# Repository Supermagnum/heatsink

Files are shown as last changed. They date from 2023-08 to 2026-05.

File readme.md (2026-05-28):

# DIY Liquid Cooling Suit

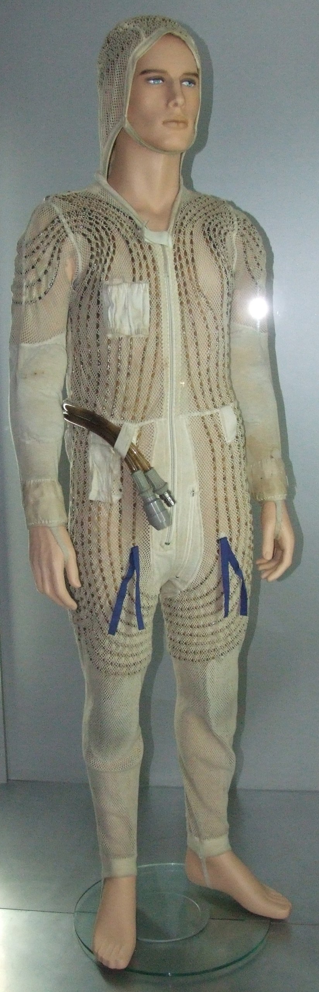
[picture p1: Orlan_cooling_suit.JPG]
Cooling Suit 1


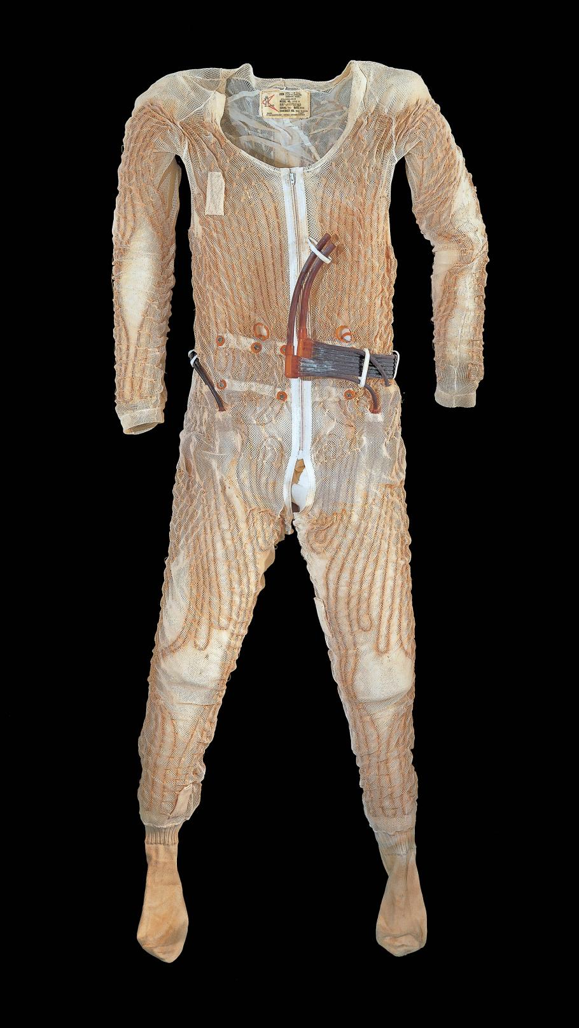
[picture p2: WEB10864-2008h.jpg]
Cooling Suit 2


Those are cooling suits, used in the lowest layer on space suits.
It has hoses for circulation of cooling medium. 
A single layer of fabric may be used, with the tubing either on the inside directly contacting the wearer's skin, or on the outside separated by the fabric. If two layers of fabric are used, stitched channels can be formed which enclose the tubing between the two fabric layers. Where flame resistance is needed, the garment may be constructed out of materials such as nomex. 
If anyone has seen the apollo 13 movie, the boxes carried by the astronauts on the way to the space capsule is a heat exchanger that provides cooling until the suits can be hooked up to the capsules internal cooling system.
That box also provides O2.

I think that NASA just used ice, battery and a pump in those boxes, and you need the capacity to at least transport 200W because the human body generates about 100W. One could rip out the heat exchanger from a car, the bit who heats air, make the suit out of spandex and sew in loops. Mesh cloth or mesh garments are also suitable. 
A radiator for a CPU liquid cooler should be ideal. Hook that up to a aquarium pump or similar, and the heat exchanger/radiator that goes in a bucket of ice cubes or phase shifting material and water. The pump will need to be able to flow around 4 liters per minute, and must run on 12V and accept PWM control.

The cooling loop is made of 
6 pvc hoses in parallel, measuring 6 mm ØID x 9 mm ØOD, length 4 meters per hose. Total internal surface of the hoses is 4524.7 cm². External surface 6789.6 cm2. The heat exchanger as well as hoses and pump contain 3 liters of inhibited propylene glycol and water mix (25–30%). Brass or metal connectors, hose barbs, and hose clamps should be used. Two manifolds are required — one for liquid distribution and one for collection — built from T-pieces, elbows, and other fittings (see [Coolant plumbing](#coolant-plumbing) below).

## Table of contents

- [Thermal Calculations](#thermal-calculations)
  - [Cooling 3 liters from 40°C to 18°C](#cooling-3-liters-of-waterglycol-from-40c-to-18c-in-150-seconds)
  - [Ice as a cooling medium](#ice-as-a-cooling-medium)
  - [Maintaining 18°C coolant temperature](#maintaining-18c-coolant-temperature)
  - [Liquid-to-ice heat exchanger](#liquid-to-ice-heat-exchanger)
- [Phase-Change Materials](#phase-change-materials)
- [Temperature Control](#temperature-control)
  - [Coolant options](#coolant-options)
  - [Preliminary Arduino Firmware](#preliminary-arduino-firmware)
- [Required Hardware](#required-hardware)
- [Electronics component list](component-list.md)
  - [Assembly instructions](component-list.md#assembly-instructions)
  - [Board placement guide (arduino-shield.jpg)](component-list.md#board-placement-guide)
  - [Ordering the PCB from Gerber files](component-list.md#ordering-the-pcb-from-gerber-files)
  - [Soldering and wire splicing](component-list.md#soldering-and-wire-splicing)
  - [How to solder (NASA reference)](component-list.md#how-to-solder)
  - [How to splice wire properly](component-list.md#how-to-splice-wire-properly)
  - [Heat-shrink on splices](component-list.md#heat-shrink-on-splices)
- [Wiring Diagram](#wiring-diagram)
- [12V Power Setup](#12v-power-setup)
  - [12V DC safety and dry locations](#12v-dc-safety-and-dry-locations)
- [Container Setup](#container-setup)
- [Suit Fabric](#suit-fabric)
- [Coolant plumbing](#coolant-plumbing)
- [Pump Selection](#pump-selection)

---

## Thermal Calculations

### Cooling 3 liters of water/glycol from 40°C to 18°C in 150 seconds

How much heat must be removed:

Q = mc∆T  
m = 3 kg  
Specific heat capacity of water = 4.18 J/g°C  
Temperature change: 40 - 18 = 22°C

Q = 3 kg × 4180 J/kg°C × 22°C = **275,880 J**

This means the heat exchanger removes 275,880 joules of heat from the cooling loop in 150 seconds.

To convert joules into watts: Joules / time in seconds = **~1,848W** during initial cooldown.

---

### Ice as a cooling medium

To remove 1848.8 watts of energy from 3 liters of water at 40°C over 150 seconds:

Q = P × t = 1848.8 W × 150 s = **277,320 J**

Mass of water being cooled:

m = Q / (c × ΔT) = 277320 / (4.18 × 40) ≈ **1.658 kg**

So approximately 1.65 kilograms of ice would be needed for the initial cooldown phase.

It will take approximately 42.86 seconds to remove 275,880 joules of heat with a flow rate of 5 liters per minute.

---

### Maintaining 18°C coolant temperature

With ambient air temperature at 40°C:

ΔT_initial = 40°C - 18°C = 22°C

m_ice = (m × c × ΔT_initial) / L_f  
m_ice = (3 kg × 4186 J/kg°C × 22°C) / 334,000 J/kg ≈ **0.827 kg per hour**

Including 100W body heat: approximately **~2 kg of ice per hour** is needed.  
Flow rate for maintenance: **~2.5 liters per minute**.

---

### Liquid-to-ice heat exchanger

To extract 275,880 J of heat from ice over 150 seconds using 10mm OD / 0.8mm wall copper tube with a ΔT of 40°C and convective heat transfer coefficient of 200 W/m²·K:

Required copper tube length: approximately **7.32 meters**  
Inner surface: 1.848 m²  
Outer surface: 2.198 m²

---

## Phase-Change Materials

I suggest using Cold Gel Packs, Campingaz or similar brand as they reportedly last longer than ice cubes.

You can make something similar yourself:  
https://m.youtube.com/watch?v=Nqxjfp4Gi0k

- Heat capacity of the salt/water mixture: approximately **5,451.5 J/°C**
- Latent heat: approximately **3.39 J/g°C**
- Total weight of mixture: **1,695 grams**
- Be aware that it might expand slightly when frozen.
- Heat capacity of 1,695 grams of water ice: approximately **3,543.55 J/°C**

Also look at:  
https://www.cryopak.com/solutions/refrigerants/phase-change-materials/phase-5/

- Heat capacity of 2 kg mixture: approximately **6,432.92 J/°C**
- Heat capacity of 2 kg water ice: **4,180 J/°C**
- 2 kg of the mixture will last approximately **3 hours** — much better than water ice.

---

## Temperature Control

To keep coolant at 18°C (0°C coolant is uncomfortable and risks hypothermia):

Use an automotive NTC temperature sensor and an Arduino to control temperature. Sensor datasheet: [Bosch M12 NTC temperature sensor (PDF)](https://www.bosch-motorsport.com/content/downloads/Raceparts/Resources/pdf/Data%20sheet_70101387_Temperature_Sensor_NTC_M12.pdf)

Arduino shield schematic: [arduino-shield.pdf](arduino-shield/arduino-shield.pdf) ([shield project folder](arduino-shield/))

Mount the Bosch M12 NTC in the **collection manifold** (return side), as close to the suit as possible — **not in the ice container**. This measures warm coolant leaving the suit for pump control. Use PWM to regulate pump speed from that reading.

Why **inhibited propylene glycol** and water? The ice bath and phase-change blocks can drive slush **below 0°C** at the heat exchanger. A **25–30% PG mix** keeps the loop liquid while staying thin enough to pump through 6 mm hoses. Unlike ethylene glycol antifreeze, propylene glycol is **biodegradable and low-toxicity** — a better fit near a wearable loop (still not for drinking). Use secure hose barbs and clamps, pressure-test the loop, and increase PG percentage only if slush goes colder than your mix rating.

### Coolant options

#### Recommended — inhibited propylene glycol + water (25–30% mix)

**Best balance of cost, safety, and compatibility for this build.**

| Property | Detail |
| --- | --- |
| **Toxicity** | Non-toxic, food-grade safe. Used in RVs, food processing, and HVAC. Unlike ethylene glycol, PG is biodegradable and presents a much lower hazard to people and animals if spilled. |
| **Hose / seal compatibility** | Compatible with typical cooling-system plastics and elastomers — PVC hose, pump seals, and brass barbs used in this project. |
| **Freeze point** | ~**−10°C at 25%** PG — enough margin for light sub-zero slush without the extra viscosity and pumping cost of a 50% mix. Use **30%** if you need more headroom. |
| **Electrical** | **Not dielectric** — conductivity is typically **>2,000 µS/cm** (water-based, conductive). Fine for a pumped hose loop; do not use near bare electronics expecting insulation. |
| **Cost / availability** | Cheapest practical option. Sold as pre-mixed **inhibited** PG antifreeze under names such as **DOWFROST**, **AMSOIL ANT**, **Cryo-Tek**, or generic **RV / marine antifreeze** at hardware and auto stores. Confirm the label says **propylene glycol**, not ethylene glycol. |

Mix with **distilled water** if buying full-strength concentrate; follow the label for your target freeze point.

#### Optional — ElectroCool and similar synthetic fluids

**ElectroCool** (Engineered Fluids) and similar **dielectric** immersion coolants are non-conductive and wash off with soap and water, but they are **much more expensive** and designed for electronics immersion — not as a default for this PVC-hose suit loop. Only consider if you validate compatibility with every hose, pump seal, and fitting, and accept the higher fluid cost.

#### Other alternatives

| Fluid | Notes |
| --- | --- |
| **USP / food-grade PG + water (DIY mix)** | Same family as above; buy PG concentrate and mix yourself. Lowest unit cost. |
| **Glycerol (glycerin) + water** | Non-toxic and biodegradable. Higher viscosity — may reduce flow in 6 mm hoses; weaker freeze protection per percent than PG. |
| **Potassium acetate / formate HTF** | Used in some commercial low-toxicity antifreeze systems. Verify pump, hose, and brass compatibility before use. |

#### Not recommended for a wearable loop

- **Ethylene glycol** (standard automotive antifreeze) — effective antifreeze but **acutely toxic**
- **Legacy PFAS / fluorinated fluids** — environmental persistence and regulatory phase-out
- **Plain water** — inadequate when slush goes below 0°C at the heat exchanger

#### Fill and service

- Use **distilled water** for mixing; tap water minerals cause scale and biofilm
- Pressure-test after fill; monitor for leaks on first runs (see [Coolant plumbing](#coolant-plumbing))
- Label the container and suit loop as containing glycol — not potable

### Preliminary Arduino Firmware

Two **momentary** switches adjust coolant temperature between 15°C and 25°C in 5°C steps (up/down).  
A **maintained toggle** switch on D4 enables manual pump override (full PWM on D9); off returns to automatic temperature control.  
Outputs on the [Arduino shield](arduino-shield/arduino-shield.pdf):
- **D9 → Q1 (TIP120):** pump PWM (temperature-controlled, or manual override via D4)
- **D7:** buzzer — out-of-ice alarm (>30°C for 2 minutes)
- **D8 → Q2 (TIP120):** spare 12V output (not used in current firmware)

LCD shows: target temperature, sensed temperature, current pump PWM.

Firmware repository:  
https://github.com/Supermagnum/heatsink/tree/main/firmware

---

## Required Hardware

1. **Arduino Uno R3** — bottom of the stack; see [component list](component-list.md)
2. [Heatsink control shield](arduino-shield/arduino-shield.pdf) — stacks on the Uno; [placement diagram](arduino-shield/arduino-shield.jpg) shows part positions, diode direction, and **+** wire marks. Order bare PCBs from [`arduino-shield/gerbers/`](arduino-shield/gerbers/) ([how to submit Gerbers](component-list.md#ordering-the-pcb-from-gerber-files)), then follow [assembly instructions](component-list.md#assembly-instructions). New to soldering? **20 W iron** and NASA/splice guides in [component list — Soldering and wire splicing](component-list.md#soldering-and-wire-splicing)
3. **LCD shield, 20×4, no buttons** — HD44780 display-only shield on top of the stack (not an LCD Keypad Shield)
4. NTC thermistor, [Bosch M12](https://www.bosch-motorsport.com/content/downloads/Raceparts/Resources/pdf/Data%20sheet_70101387_Temperature_Sensor_NTC_M12.pdf) (see [Coolant plumbing](#coolant-plumbing) for mounting)
5. **R1** — **MFP50SBBE52-50K** (50 kΩ, 0.1%) — DigiKey **MFP50SBBE52-50K-ND**
6. **D1–D3** — three **1N5407RL** flyback diodes — DigiKey **1N5407RL-ND** (or **1N5407RLG-ND** if unavailable)
7. **2× M3 nylon bolt and nut** — mount **Q1** and **Q2** tabs only; **no metal** hardware (12 V)
8. Shield stacking headers — DigiKey **1528-1074-ND** (Adafruit #85), one kit per bare control shield for Uno/LCD stack ([full DigiKey list](component-list.md#digikey-quick-order-bare-shield-populate))
9. Three **panel switches** on **SW1–SW3** (1×3 headers): two **100SP4T1B2M2QE** momentary (temp up/down), one **ANT13SECQE** maintained toggle (pump manual/auto). **Switch guards** (100SP / ANT compatible) recommended to prevent accidental actuation — especially on SW3
10. 12V submersible pump (4–5 L/min) — switched by **Q1 TIP120 on D9** on the control shield (max **5A**)
11. Optional: **5A inline fuses** on each 12V power cable branch (see [12V Power Setup](#12v-power-setup))
12. Crimped leads / screw terminals for panel switches, NTC, and 12 V — see [component list](component-list.md)
13. Hose clamps
14. Assorted T-pieces, elbows, connectors, adapters, and tube barbs (metal or PETG — see [Coolant plumbing](#coolant-plumbing))
15. Inhibited propylene glycol antifreeze (propylene, not ethylene) for 25–30% coolant mix
16. Liquid gasket or PTFE thread tape for sealed joints
17. Optional: small valves to control "zones"

### Arduino stack and connections

**Stack (bottom → top):** Arduino Uno R3 → heatsink control shield → **LCD shield without buttons**. Panel switches and NTC connect to the control shield headers/terminals only.

- Bosch M12 NTC (TH1) and 50K resistor (R1) form a voltage divider on A0; AREF feeds the divider top and sets the ADC reference
- **LCD shield** (20×4, HD44780, **no keypad**) on D12, D11, D10, D6, D5, D13 — see [Wiring Diagram](#wiring-diagram)
- Switches wired **pin → switch → GND** (active when grounded); firmware enables internal pull-ups on D2, D3, and D4
- **D2 / D3:** momentary — one temperature step per actuation
- **D4:** maintained toggle — ON = manual pump override, OFF = automatic
- D9 PWM drives **Q1 TIP120** on the shield — low-side switch for the pump (up to 5A)
- D7 drives the **buzzer** alarm output
- D8 drives **Q2 TIP120** for the spare 12V output
- Q1 and Q2 are TO-220 packages clamped to **built-in copper thermal zones** with **M3 nylon bolt and nut** each — **no metal mounting hardware** (12 V on the tab). **No add-on heatsinks**; the PCB spreads heat from the transistor tabs

---

## Wiring Diagram

Signal and power connections for the [Arduino shield](arduino-shield/arduino-shield.pdf). Ground all 12V loads to a common bus.

```mermaid
graph TD
    PSU["12V PSU / Battery"]

    PSU -->|12V| ARD["Arduino Uno\n+ control shield"]
    PSU -->|12V| Q1["TIP120 Q1\npump D9"]
    PSU -->|12V| Q2["TIP120 Q2\nspare D8"]

    ARD -->|D9 PWM| Q1
    Q1 --> PUMP["Submersible pump\n4–5 L/min"]

    ARD -->|D7| BUZ["Buzzer\nout-of-ice alarm"]
    ARD -->|D8| Q2
    Q2 --> SPARE["Spare 12V load\n(no firmware control)"]

    AREF["AREF-voltage"] -->|divider top + ADC ref| ARD
    AREF --> R1["R1 50K"]
    R1 -->|Vsense A0| ARD
    R1 --- TH1["TH1 Bosch M12 NTC\ncollection manifold\nat suit"]
    TH1 --> GND["Common GND"]

    SW1["SW1 Temp up\nmomentary"] -->|D2 — GND when closed| ARD
    SW2["SW2 Temp down\nmomentary"] -->|D3 — GND when closed| ARD
    SW3["SW3 Pump override\nmaintained toggle"] -->|D4 — GND when ON| ARD

    LCD["LCD 20x4"] -->|D12 RS, D11 E, D10 D4\nD6 D5, D13 D7| ARD

    ARD --- GND
    Q1 --- GND
    Q2 --- GND
    PUMP --- GND
    PSU --- GND
```

### Pin summary

| Pin | Function |
| --- | --- |
| A0 | NTC sense (R1 / TH1 junction) |
| AREF | Divider reference (same rail as R1 top) |
| D2 | SW1 momentary — target temperature up (+5°C per actuation) |
| D3 | SW2 momentary — target temperature down (−5°C per actuation) |
| D4 | SW3 maintained toggle — manual pump override (ON = full PWM) |
| D7 | Buzzer alarm (auto, >30°C for 2 min) |
| D8 | Q2 spare 12V output |
| D9 | Pump PWM via Q1 TIP120 |
| D5, D6, D10–D13 | LCD data and control |

**Switch wiring:** Panel switches **100SP4T1B2M2QE** (SW1, SW2) and **ANT13SECQE** (SW3) connect via **SW1–SW3** headers: **pin → switch → GND**. Internal pull-ups are enabled in firmware (`INPUT_PULLUP`); closed / ON = LOW. Add **switch guards** (100SP / ANT series) on the panel to reduce accidental toggles — especially on the pump override (SW3).

**NTC placement:** TH1 threads into the **collection manifold** on the return path, positioned **as close to the suit as practical** — not in the insulated container. The sensor cable runs back to the Arduino shield.

**NTC divider:** `AREF-voltage — R1 (50K) — A0 — TH1 (Bosch M12) — GND`. Firmware calls `analogReference(EXTERNAL)` so ADC readings match the divider supply.

**Pump override (SW3 / D4):** Maintained toggle — **ON** = full pump PWM via Q1; **OFF** = automatic temperature control.

**Temp switches (SW1 / SW2):** Momentary — one ±5°C step per actuation (debounced).

**12V loads:** Pump current flows through **Q1** on the shield — not through Arduino I/O pins directly. Q2 switches the spare load. D7 drives the buzzer. Add a **5A inline fuse** on each 12V feed (Arduino, pump/Q1, Q2) if not already fused at the battery.

---

## 12V Power Setup

```mermaid
graph LR
    BAT["12V Battery\nor PSU"]

    BAT --> FUSE_MAIN["Fuse 5A max\n(battery lead)"]
    FUSE_MAIN --> BUS["12V Distribution Bus"]

    BUS --> FUSE_A["Fuse 5A"] --> ARD["Arduino + LCD\n(~1A max)"]
    BUS --> FUSE_B["Fuse 5A"] --> PUMP_RAIL["Q1 pump rail\n(up to 5A)"]
    BUS --> FUSE_C["Fuse 5A"] --> Q2_RAIL["Q2 spare output"]

    GND["Common Ground Bus"] --- ARD
    GND --- PUMP_RAIL
    GND --- Q2_RAIL
    GND --- BAT
```

**Notes:**
- All components share a common ground
- Use **5A inline fuses maximum** on each 12V power cable branch (battery lead plus Arduino, pump/Q1, and Q2 feeds). Do not exceed 5A fuse rating on these cables
- The Arduino can be powered directly from 12V via its barrel jack (onboard regulator handles 5V/3.3V internally)
- The pump is switched by **Q1 TIP120 on the control shield** (D9 PWM) — do not connect pump current through Arduino pins
- Q1 and Q2 are rated up to 5A; size the pump accordingly
- Use appropriately rated wire gauge: 1.5mm² minimum for pump circuit, 0.5mm² for signal wiring
- TIP120 transistors (Q1, Q2) mount to **copper thermal zones** on the shield PCB with **M3 nylon** bolt and nut — **do not use metal** fasteners at the tabs; no separate heatsinks needed

**Battery sizing (portable use):**
- Pump draw: approximately 3-5A at 12V = 36-60W (Q1 TIP120 and pump fuse at **5A max**)
- Arduino + transistors + LCD: approximately 0.3A = 4W
- Total: approximately 4-5A continuous with a 5A fuse on the pump feed at the upper limit — avoid sustained overload
- A 20Ah 12V LiFePO4 battery gives approximately 3-4 hours runtime, matching the phase-change block duration

### 12V DC safety and dry locations

12 V is low enough that it is not mains shock hazard, but this system can still draw **several amps continuously**. Treat wiring like any other DC power installation: fused, correct gauge, and kept away from coolant and condensation.

**Electrical safety (12 V DC):**

- **Fuse every branch** at **5 A maximum** (battery lead plus Arduino, pump/Q1, and Q2). Fuses protect wire and battery from shorts — not optional.
- **Wire gauge:** **1.5 mm² minimum** on pump and battery feeds; **0.5 mm²** for signals. Undersized wire heats up under 3–5 A load.
- **Polarity:** Double-check **+12 V and GND** before connecting the battery. Reverse polarity can destroy the Arduino, shield, and pump controller.
- **One common ground** for battery, Arduino stack, pump return, and Q1/Q2 switching. Do not rely on the suit or frame as a ground path.
- **Pump current through Q1 only** — never through Arduino pins. The TIP120 switches the low side; the pump (+) comes from the fused 12 V bus.
- **Q1 / Q2 tab fasteners:** **M3 nylon** bolt and nut only — **no metal** at the transistor tabs (live **12 V**).
- **De-energize for wiring** — disconnect the battery or remove fuses when crimping, moving terminals, or opening the control enclosure.
- **Strain relief and insulation** — no bare copper at the panel or inside the box; use screw terminals or crimps where possible. **Every soldered splice must be covered with heat-shrink** (the [splice reference video](component-list.md#soldering-and-wire-splicing) does not show this step). Tie down cables so connectors are not pulled loose in use.
- **Coolant is conductive** — a glycol leak onto bare 12 V terminals can cause shorts, heating, or fire. Keep splices out of drip paths; wipe spills before re-energizing.
- **Batteries:** Use a proper 12 V pack (e.g. LiFePO4) with a BMS or charger matched to the chemistry. Do not short the terminals; store and charge in a dry, ventilated area away from flammable material.

**Keep dry — control unit and related electronics:**

Mount the **control unit** in a **dry enclosure** outside the ice container. It consists of:

| Keep dry | Location |
| --- | --- |
| **Arduino Uno R3 + heatsink control shield + LCD shield** (stacked) | Inside a sealed project box or small case on the suit harness, belt, or backpack — **not** in the cooler |
| **12 V battery** (if portable) | Same dry area as the control unit; protect from sweat, rain, and spills |
| **Panel switches** (SW1–SW3) | On the operator panel; guards help mechanically — use splash-aware routing if exposed |
| **NTC cable (TH1)** | Sensor threads into the **wet** manifold; only the **M12 sensor tip** sees coolant. The cable and connector back to the shield must stay **dry** — route upward from the manifold and seal the panel penetration |

**Allowed to get wet (by design):**

| Wet location | Parts |
| --- | --- |
| **Inside the insulated cooler** | Submersible pump, radiator, ice/slush, coolant hoses through the lid |
| **Suit loop** | PVC hoses, manifolds, fittings, and the Bosch M12 sensing element in the collection manifold |

Only **12 V pump power** and **coolant hoses** should pass through the cooler lid (grommeted or sealed). Run signal and Arduino power from the **dry control box** — do not submerge the stack, battery, or unsealed junctions. If the enclosure may see humidity, use vented or IP-rated boxes and keep connectors inside the lid line.

See also [Container Setup](#container-setup) for lid penetrations and [component list](component-list.md) for stack parts.

---

## Container Setup

```mermaid
graph TD
    LID["Insulated Cooler Lid\n(15-20 litre cooler)"]

    LID -->|Sealed penetrations| HOSE_IN["Coolant hose IN\n(warm return from suit)"]
    LID -->|Sealed penetrations| HOSE_OUT["Coolant hose OUT\n(chilled supply to suit)"]
    LID -->|Sealed penetrations| POWER["12V power cable\n(to pump)"]

    subgraph CONTAINER["Insulated Container (interior)"]
        RAD["240mm PC Radiator\n(submerged, bottom-mounted)"]
        PUMP_S["Submersible Pump\n(brushless 12V DC)"]
        ICE["Ice / Phase-Change Blocks\n(~2kg per hour runtime)"]
        WATER["Water filling gaps\nfor thermal contact"]
        RAD --- ICE
        PUMP_S --- ICE
        ICE --- WATER
    end

    HOSE_IN -->|warm coolant from suit| RAD
    RAD -->|cooled coolant| PUMP_S
    PUMP_S -->|cooled coolant| HOSE_OUT
```

**Container notes:**
- Use a quality foam-insulated cooler (camping/outdoor grade) with a good lid seal
- The radiator sits at the bottom, fully submerged in ice water — this gives 5-10× better heat transfer than air cooling
- The submersible pump also sits inside the container, drawing chilled water/glycol
- All lid penetrations (hoses and **pump 12 V power only**) should be sealed with silicone or grommets to prevent warm air ingress and leaks
- The **Arduino control unit** (stack, battery, dry wiring) stays **outside** the cooler — see [12V DC safety and dry locations](#12v-dc-safety-and-dry-locations)
- Fill gaps around ice/phase-change blocks with water to maximise thermal contact with the radiator
- The NTC sensor is **not** mounted in the container — it sits in the **collection manifold at the suit** (see [Coolant plumbing](#coolant-plumbing))

**Radiator sizing:**
- A 240mm radiator (air-rated ~300W) performs at approximately 1,500-3,000W when submerged in ice water
- This comfortably covers the 1,848W initial cooldown load and the 100W maintenance load
- A 360mm radiator provides additional headroom, particularly useful with phase-change blocks which have less uniform surface contact than liquid ice water

---

## Suit Fabric

**Recommended: Cotton mesh**

Cotton mesh is the best choice for this application because:
- Breathable open weave allows direct skin contact with the cooling tubes
- Cotton is comfortable and non-irritating against skin during extended wear
- Natural fibre — does not trap heat against the body
- Easy to sew channels or loops for routing the 6mm/9mm PVC hoses
- Washable and durable

**Construction:**
- Sew hose channels directly into the mesh using a zigzag or channel stitch
- Route hoses in parallel loops across the torso, back, and limbs as needed
- Connect the six suit hoses to distribution and collection manifolds (see [Coolant plumbing](#coolant-plumbing))
- Optional zone valves allow sections of the suit to be isolated, reducing flow to areas not needed

---

## Coolant plumbing

Two manifolds are needed: one splits flow from the supply line into the six parallel suit hoses, and one merges the return lines back toward the heat exchanger.

**NTC sensor placement:**
- Install the Bosch M12 sensor (TH1) in the **collection manifold** — the return manifold where warmed coolant from the suit hoses combines
- Place the port **as close to the suit as possible**, before the long hose run back to the container
- The sensor measures coolant temperature **leaving the suit**, which is what the Arduino uses for pump control — not the chilled fluid inside the ice box

**Fittings:**
- Several T-pieces, elbows, and connectors sized for 6 mm ID / 9 mm OD hose
- Metal (brass) barbs and fittings are the most durable option
- Manifolds can alternatively be **3D printed in PETG** if wall thickness and infill are high enough for pressure (typically 40% infill or higher, with solid perimeters around barb ports)

**Bosch M12 sensor mounting (metal route):**
- A suitable **drill and M12 tap** are required to thread the port for the Bosch M12 sensor
- Seal threads with **liquid gasket** or **PTFE tape**

**Assembly and testing:**
- Use liquid gasket or PTFE tape on all threaded connections
- **Pressure-test** the completed loop before use and **monitor for leaks** during initial runs
- Fix any weeping joints before relying on the system in service
- Electronics build and bench test: [assembly instructions](component-list.md#assembly-instructions) (Steps 5–6)

---

## Pump Selection

**Requirements:**
- 12V DC brushless, submersible rated
- Flow rate: 4-5 liters/minute (minimum)
- Continuous duty rated
- PWM controllable (dedicated PWM signal wire preferred)
- ½ inch inlet and outlet
- Compatible with inhibited propylene glycol and water mix (25–30%)

**Search terms:**
- "12V DC brushless submersible pump PWM 5LPM"
- "12V DC pump 300LPH PWM control"

Check aquarium suppliers, solar pump suppliers, and irrigation suppliers. Gear and diaphragm pumps handle PWM better than centrifugal types at this flow rate. Centrifugal pumps require priming and cannot be controlled as precisely.

**PWM control note:** The shield uses **Q1 TIP120** on D9 for low-side PWM of the pump. Many brushless pumps tolerate slow PWM on the power side; if the pump stutters, try a pump with a dedicated PWM input wire or add a smoothing capacitor on the pump supply. Stay within the **5A** Q1 and fuse limit.

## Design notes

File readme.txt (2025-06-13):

A DIY cooling suit idea:
Cooling Suit 1

Cooling Suit 2

Those are cooling suits, used in the lowest layer on space suits.
It has hoses for circulation of cooling medium. 
A single layer of fabric may be used, with the tubing either on the inside directly contacting the wearer's skin, or on the outside separated by the fabric. If two layers of fabric are used, stitched channels can be formed which enclose the tubing between the two fabric layers. Where flame resistance is needed, the garment may be constructed out of materials such as nomex. 
If anyone has seen the apollo 13 movie, the boxes carried by  the astronauts on the way to the space capsule is a heat exhanger that provides cooling until the suits can be hooked up to the capsules internal cooling system.
That box also provides O2.

I think that NASA just used ice,battery and a pump in those boxes, and you need the capacity to at least transport 200W because the human body generates about 100W. One could rip out the heat exhanger from a car, the bit who heats air, make the suit out of spandex and sew in loops.Mesh cloth or mesh garments are also suitable. 
A radiator for a CPU liquid cooler should be ideal.Hook that up to a aquarium pump or similar, and the heat exhanger/radiator that goes in a bucket of ice cubes or phase shifting material and water. The pump will need to be able to flow around 4 liters per minute, and must run on 12V and accept PWM control.

The cooling loop is made of 
6 pvc hoses in parallel, measuring 6 mm ØID x 9 mm ØOD, length 4 meters per hose. Total internal surface of the hoses is 4524.7 cm². External surface 6789.6 cm2. The heat exchanger as well as hoses and pump contain 3 liters of water/glycol mix. Brass or metal connectors,hose barbs  liquid distribution manifolds with hose clamps should be used.

Thermal calculation examples:
One cools 3 liters of water/glycol from 40 degrees to 18 degrees in 150 seconds.

How much heat must be removed:
Q = mc∆T
m = 3 kg.

specific heat capacity of water is 4.18 J/g°C, one liter of water is 1000 grams.

And we know that the temperature change of the water is 40 - 18 = 22 °C.

So by entering these values into the formula we get:
Q = 3 kg x 4180 J/kg°C x 22 °C Q = 275880 J

This means that the heat exchanger removes 275880 joules of heat from the cooling loop in 150 seconds.

To convert joules into watts= Joules/time in seconds.

Ice as a cooling medium for the coolant loop:

To calculate the amount of ice needed to remove 1848.8 watts of energy from 3 liters of water at 40 degrees Celsius over a period of 150 seconds, we can use the formula:

Q = P * t

Where:
Q = Heat energy (in Joules)
P = Power (in watts)
t = Time (in seconds)

Given that P = 1848.8 watts and t = 150 seconds, we can calculate Q:

Q = 1848.8 W * 150 s
Q = 277320 J

Now, let's use the specific heat capacity formula to determine the mass of water being cooled:

Q = m * c * ΔT

Where:
Q = Heat energy (in Joules) = 277320 J
m = Mass of the substance (in kilograms)
c = Specific heat capacity of water (approximately 4.18 J/g°C)
ΔT = Change in temperature (final temperature - initial temperature)

We know that the initial temperature of water is 40°C and it's being cooled to 0°C  in this case (assuming ice temperature). Solving for the mass (m):

m = Q / (c * ΔT)
m = 277320 J / (4.18 J/g°C * 40°C)
m ≈ 1658,6 g

Converting grams to kilograms:

m ≈ 1.658 kg

So, approximately 1.65 kilograms of ice (equivalent to the mass of water being cooled) would be needed to remove 1848.8 watts of energy from 3 liters of water/glycol mix at 40 degrees Celsius over a period of 150 seconds. 

It will take approximately 42.86 seconds to remove 275,880 joules of heat with a flow rate of 5 liters per minute.

Now, when the coolant has reached 18 degrees Celsius say we want to keep it at that temperature.

How one can calculate the amounts of ice needed per hour to keep the coolant liquid at 18 degrees Celsius if the ambient air temperature is 40 degrees Celsius:
First, we need to calculate the initial temperature difference between the water and the ambient air:

ΔT_initial = 40°C - 18°C = 22°C

Next, we calculate the heat transfer required to bring the water to its final temperature:

Q = m * c * ΔT_initial

Since we're interested in how much ice is needed to absorb this heat, we can also equate it to the heat absorbed by melting ice:

Q = m_ice * L_f

Where:
- m_ice is the mass of ice (in kilograms)
- L_f is the heat of fusion of ice (334,000 J/kg)

Combining the two equations:

m_ice * L_f = m * c * ΔT_initial

Solving for m_ice:

m_ice = (m * c * ΔT_initial) / L_f

Given that the density of water is approximately 1000 kg/m³, the mass of 3 liters of water is 3 kg.

m_ice = (3 kg * 4186 J/kg°C * 22°C) / 334000 J/kg ≈ 0,827 kg

So, approximately 0,827 kilograms ( 827 grams) of ice per hour would be needed to keep 3 liters of water at 18 degrees Celsius when the ambient air temperature is 40 degrees Celsius.
But, one needs to include that a human body generates maximum 100W of heat, so the mass of ice needed per hour is ≈ 2 kg
The flow rate for that is around 2.5 liters per minute.

Liquid to ice heat exhanger:
To extract 275,880 J of heat from water ice over 150 seconds using a 10 mm OD and 0.8 mm wall thickness copper tube with a temperature difference of 40 degrees Celsius and a convective heat transfer coefficient of 200 W/m²·K, the required length of the copper tube is approximately 7.32 meters. That is a inner surface of 1,848 square metres, and 2,198 square metres.

Keep in mind that these calculations assumes ideal heat transfer and doesn't consider other factors that might affect the cooling process, loss to the environment, heat exhanger loss and so on..

They also assumes that I haven't made any mathematical bloopers.

I suggest using Cold Gel Packs, Campingaz or similar brand as they supposedly lasts longer that ice cubes.

You can make something similar yourself:
https://m.youtube.com/watch?v=Nqxjfp4Gi0k
The heat capacity of the salts and water mixture is approximately 5451.5 J/°C.
In latent heat that is around 
3.39J/g°C.
The total weight of the mixture is 1695 grams. Be aware that it might expand slightly when frozen.
The heat capacity of 1695 grams of water ice is approximately 3543.55 J/°C.

Also,look at:
https://www.thermalcustompackaging.com/pcm/

The heat capacity of the 2 kg mixture is approximately 6432.92 J/°C.
The heat capacity of 2 kg of water ice is 4180 J/°C.
2 kilos of the mixture will last about 3 hours.
Much better than water ice.

How does one keep the temperature of the coolant at 18 degrees Celsius, 0 degrees coolant is uncomfortable!
There's also a risk of hyperthermia!

One can use a automotive NTC temperature sensor like this, and a arduino to control the temperature:
https://www.bosch-motorsport.com/content/downloads/Raceparts/Resources/pdf/Data%20sheet_70101387_Temperature_Sensor_NTC_M12.pdf
One then can monitor the temperature of the suits output and use PWM control to  control the speed of a pump.

Why water/glycol mix? So that the liquid in the coolant loop does not freeze or turn to slush in the heat exchanger.

Preliminary firmware for Arduino and the mentioned temperature sensor:
It has two switches, to adjust the coolant temperature between 15 degrees and 25 degrees Celsius in 5 degree steps.
One for up, one for down. 
I also has another switch to start the pump.
It has 2 relay outputs, one activates if the coolant temperature goes over 30 degrees Celsius for a set time. It can be used to activate a buzzer to signal out of ice.
It also puts out the wanted temperature, sensed temperature and current pump pwm to a 4 line lcd screen.
https://github.com/Supermagnum/heatsink/tree/main/firmware

### Required Hardware:
1. Arduino board (e.g., Arduino Uno)
2. NTC thermistor, Bosch M12.
3. Resistor (50k ohms)
4. 4-line LCD (compatible with LiquidCrystal library)
5. Three guarded stsp switches (for temperature up, temperature down, and relay control)
6. Pump controlled via PWM
7. Two relays,12V
8. Breadboard and connecting wire
9.3 10K resistors.
10. hose clamps.
11. Assorted size adapters and tube barbs in metal.
12: optional small valves to control "zones".

### Connections:
- NTC thermistor and 50k resistor form a voltage divider.
- LCD connected to appropriate digital pins.
- Switches connected to digital pins with pull-down resistors.
- PWM pin connected to pump control input.
- Digital pins connected to relay control inputs.

### Notes:
1. **Debouncing**: The debounce logic ensures that button presses are not registered multiple times due to mechanical bounce.
2. **Temperature Calculation**: The resistance of the NTC is converted to a temperature value using a linear interpolation method between calibration points.
3. **PWM Control**: The PWM value is adjusted based on the difference between the target temperature and the read temperature, with a minimum PWM of 10%.
4. **LCD Display**: The LCD shows the target temperature, the read temperature, the current PWM value, and the state of the relay.

### Adjustments:
- Ensure that the LCD pin connections in the code match your actual connections.
- Modify pin numbers if you use different pins for buttons, relays, or the NTC sensor.
- If the NTC thermistor has different calibration values, adjust the `tempValues` and `resistanceValues` arrays accordingly.

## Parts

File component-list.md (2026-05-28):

# Electronics component list

Bill of materials for the Arduino control side of the liquid cooling suit. Values match the [control shield schematic](arduino-shield/arduino-shield.pdf). KiCad source files in `arduino-shield/` are maintained separately and are not edited from this repo workflow.

**Assembly goal:** stack shields on an **Arduino Uno R3** with **minimum soldering** — plug-in headers and screw terminals for field wiring; only populate/solder the control shield PCB if you order it bare. If you are new to soldering, see [Soldering and wire splicing](#soldering-and-wire-splicing) below.

## Table of contents

- [Stack (bottom to top)](#stack-bottom-to-top)
- [Core components](#core-components)
- [Control shield](#control-shield-included-in-stack)
  - [DigiKey quick order (bare shield populate)](#digikey-quick-order-bare-shield-populate)
- [Assembly instructions](#assembly-instructions)
  - [Board placement guide](#board-placement-guide)
  - [Before you start](#before-you-start)
  - [Step 1 — Populate the bare control shield](#step-1--populate-the-bare-control-shield)
  - [Step 2 — Build the Arduino stack](#step-2--build-the-arduino-stack)
  - [Step 3 — Panel switches and NTC](#step-3--panel-switches-and-ntc)
  - [Step 4 — 12 V power and pump](#step-4--12-v-power-and-pump)
  - [Step 5 — Load firmware](#step-5--load-firmware)
  - [Step 6 — Bench test](#step-6--bench-test)
- [Ordering the PCB from Gerber files](#ordering-the-pcb-from-gerber-files)
- [Wire and cable](#wire-and-cable-minimum-soldering)
- [Soldering and wire splicing](#soldering-and-wire-splicing)
  - [How to solder (NASA reference)](#how-to-solder)
  - [How to splice wire properly](#how-to-splice-wire-properly)
  - [Heat-shrink on splices](#heat-shrink-on-splices)
- [Quick wiring reference](#quick-wiring-reference)
- [Suggested order checklist](#suggested-order-checklist)
- [12 V safety and enclosure](#12-v-safety-and-enclosure)

---

## Stack (bottom to top)

| Layer | Part | Notes |
| --- | --- | --- |
| 1 | **Arduino Uno R3** | ATmega328P, 5 V logic. Powers from 12 V barrel jack or VIN when on battery. |
| 2 | **Heatsink control shield** | [arduino-shield.pdf](arduino-shield/arduino-shield.pdf) + [placement diagram](arduino-shield/arduino-shield.jpg) — stacking headers, Q1/Q2, R1, D1–D3, TH1 header, SW1–SW3 headers, buzzer, 12 V pump/spare terminals. Solder only if you receive a bare PCB. |
| 3 | **LCD shield (no buttons)** | 20×4 HD44780, **display only** — no keypad, no built-in push-buttons. Plugs onto the stack; uses D5, D6, D10–D13 (see [pin summary](readme.md#pin-summary)). Do **not** use an LCD Keypad Shield — firmware uses external panel switches on D2–D4. |

External to the stack (crimp or screw terminals, no board soldering): **three panel switches**, **Bosch M12 NTC** cable to TH1 header, **12 V** pump and power leads.

---

## Core components

| Qty | Ref | Description | Part number / spec | Notes |
| --- | --- | --- | --- | --- |
| 1 | U1 | Microcontroller | **Arduino Uno R3** | Required for direct shield stacking. |
| 1 | — | LCD shield | **20×4 HD44780 LCD shield, no buttons** | e.g. parallel “LCD2004” shield without keypad. Display-only — temp/PWM/alarm text; switches stay on the panel. |
| 1 | TH1 | NTC temperature sensor | **Bosch M12** NTC | [Datasheet (70101387)](https://www.bosch-motorsport.com/content/downloads/Raceparts/Resources/pdf/Data%20sheet_70101387_Temperature_Sensor_NTC_M12.pdf). Mount in **collection manifold** at the suit (return path), not in the ice box. Requires **M12 tap** and sealant on metal manifold. |
| 1 | R1 | Fixed resistor, top of NTC divider | **MFP50SBBE52-50K** (50 kΩ, 0.1%, 1/2 W) — DigiKey **MFP50SBBE52-50K-ND** | Solder on control shield between AREF rail and A0; TH1 from A0 to GND. |
| 3 | D1, D2, D3 | Flyback diode (inductive loads) | **1N5407RL** (DO-27, 3 A) — DigiKey **1N5407RL-ND** (or **1N5407RLG-ND** if RL is unavailable) | One each across Q1, Q2, and the spare 12 V path — cathode to +12 V, anode toward transistor collector (per [schematic](arduino-shield/arduino-shield.pdf)). |
| 2 | Q1, Q2 | NPN Darlington, low-side switch | **TIP120** (TO-220) | Q1: pump on **D9** (PWM, up to **5 A**). Q2: spare 12 V on **D8**. Mount to shield **copper thermal zones** with **nylon M3** bolt + nut each — **no metal fasteners** (12 V on tab). No add-on heatsinks. |
| 2 | — | Transistor mounting | **M3 nylon** bolt + nut (×2 sets) | One per **Q1** and **Q2** tab hole. **Do not use metal** screw/nut/washer — can short **12 V** to ground. |
| 2 | SW1, SW2 | Panel switch, momentary | **100SP4T1B2M2QE** | Temp up (D2) and temp down (D3). **Switch guard** recommended (see below). |
| 1 | SW3 | Panel switch, maintained toggle | **ANT13SECQE** | Pump manual/auto on **D4**. **Switch guard** strongly recommended — prevents accidental pump override. |
| 3 | — | Switch guard | Compatible with **100SP** / **ANT** panel switches | Optional but recommended: covers/guards that block accidental bumps (especially on SW3). Match guard to switch series and actuator type per supplier catalog. |

---

## Control shield (included in stack)

| Qty | Ref | Description | Part number / spec | Notes |
| --- | --- | --- | --- | --- |
| 1 | — | **Heatsink control shield** PCB | Gerbers in [`arduino-shield/gerbers/`](arduino-shield/gerbers/) | Bare board — populate per schematic PDF. |
| 1 | — | Shield stacking headers | **Adafruit #85** / DigiKey **1528-1074-ND** | One kit per bare shield: 2×6 + 2×8 + 1×10 long-tail stacking female for Uno R3 stack (control shield between Uno and LCD). |
| 1 | R1 | NTC divider resistor | **MFP50SBBE52-50K-ND** | Also listed under [Core components](#core-components). |
| 3 | D1–D3 | Flyback diodes | **1N5407RL-ND** (or **1N5407RLG-ND**) | Also listed under [Core components](#core-components). |
| 2 | Q1, Q2 | Darlington switches | **TIP120** + **M3 nylon** bolt/nut each | Also listed under [Core components](#core-components). **No metal** tab hardware. |
| 1 | BZ1 | Buzzer | TDK **PS1240P02BT** class, 12 mm, polarized | Alarm on **D7** (>30 °C for 2 min). |

Order assembled if you want zero soldering; on a bare PCB, solder stacking headers, TIP120 (to copper thermal zones with **nylon M3** hardware), R1, D1–D3, buzzer, and field connectors per the schematic PDF.

### DigiKey quick order (bare shield populate)

| Qty | DigiKey | Manufacturer P/N | Ref / use |
| --- | --- | --- | --- |
| 1 | [1528-1074-ND](https://www.digikey.com/en/products/result?keywords=1528-1074-ND) | Adafruit **#85** | Shield stacking headers (2×6 + 2×8 + 1×10) |
| 1 | [MFP50SBBE52-50K-ND](https://www.digikey.com/en/products/result?keywords=MFP50SBBE52-50K-ND) | MFP50SBBE52-50K | R1 — NTC divider |
| 3 | [1N5407RL-ND](https://www.digikey.com/en/products/result?keywords=1N5407RL-ND) | 1N5407RL | D1, D2, D3 — flyback (schematic value) |
| 3 | [1N5407RLG-ND](https://www.digikey.com/en/products/result?keywords=1N5407RLG-ND) | 1N5407RLG | Same as above if **1N5407RL-ND** is out of stock (lead-free replacement) |

Search DigiKey for **TIP120** and a **PS1240P02BT**-class buzzer separately; those parts are not Adafruit-line items.

See [Ordering the PCB from Gerber files](#ordering-the-pcb-from-gerber-files) to have bare boards fabricated.

---

## Assembly instructions

End-to-end build for the **Arduino control unit** (Uno + heatsink control shield + LCD shield + field wiring). Coolant plumbing, ice box, and suit hoses are covered in the [readme](readme.md) ([Coolant plumbing](readme.md#coolant-plumbing), [Container setup](readme.md#container-setup)).

### Board placement guide

Use the silkscreen labels and polarity marks on the bare PCB. This shield has **no USB** — only the **Arduino Uno** below it does. The render below is the **control shield alone** (component side up). Match its orientation: **D1** at the top of the diode column, **SW1–SW3** on the **right**, **stacking-header** holes along the long **top and bottom** edges:

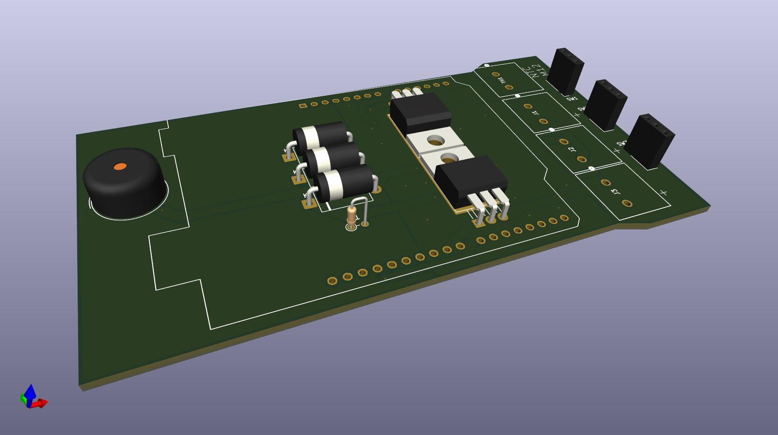
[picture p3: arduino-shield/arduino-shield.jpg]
Heatsink control shield — component placement and polarity


| Label | Location on board | What to install / connect |
| --- | --- | --- |
| **D1, D2, D3** | Left column (**D1** top, **D3** bottom) | **1N5407RL** — cathode **band toward D1** (same end as silkscreen **K** / +12 V side). |
| **R1** | Below the diode column | **MFP50SBBE52-50K**, vertical axial. |
| **BZ1** | Left side, round footprint | Polarized buzzer — **+** pin to marked **+** on silkscreen. |
| **Q1, Q2** | Centre, on copper thermal areas | **TIP120** — package **flat on the board**, metal tab on copper, leads bent **90°** toward the **bottom** long edge (same side as in the image). **Q1** above **Q2**. Secure each tab with an **M3 nylon bolt and nut** through the tab hole — **never metal** (12 V present). |
| **SW1, SW2, SW3** | Right edge, **three 3-pin blocks** in a row (top → bottom) | **1×3** sockets for panel switch cables — see [Step 3](#step-3--panel-switches-and-ntc). |
| **TH1** | Four 2-pin blocks, left of SW column (top block) | NTC cable — **+** silkscreen marks sense/reference; other pin is GND. |
| **J1, J2, J3** | Next blocks below **TH1** | Screw terminals — land **+12 V** on pins marked **+**; other pin is switched load or return per [Step 4](#step-4--12-v-power-and-pump). |
| *(headers)* | Top and bottom long rows | **1528-1074-ND** stacking headers for Uno / LCD stack. |

Every part has its own ref label (**SW1**, **Q1**, etc.) printed on the board — match those labels when placing parts.

### Before you start

**Tools:** 20 W soldering iron, rosin-core solder, damp sponge, flush cutters, small screwdriver for screw terminals, crimp tool (optional), multimeter, **2× M3 nylon bolt + nut** for **Q1** and **Q2** (no metal hardware at transistor tabs).

**Parts:** Complete the [suggested order checklist](#suggested-order-checklist) and [DigiKey quick order](#digikey-quick-order-bare-shield-populate) if you are populating a bare shield.

**Reference:** [arduino-shield.jpg](arduino-shield/arduino-shield.jpg) for placement and polarity; [arduino-shield.pdf](arduino-shield/arduino-shield.pdf) for electrical nets.

**Safety:** Work **de-energized** — no battery connected until [Step 6](#step-6--bench-test). See [12 V safety and enclosure](#12-v-safety-and-enclosure) and [Soldering and wire splicing](#soldering-and-wire-splicing).

**Skip PCB soldering** if someone else populated the control shield for you — start at [Step 2](#step-2--build-the-arduino-stack).

### Step 1 — Populate the bare control shield

Only when you received a **bare PCB** from the [Gerber order](#ordering-the-pcb-from-gerber-files). Follow the [board placement guide](#board-placement-guide) and silkscreen labels. Suggested solder order (shortest parts first, then connectors, then tall headers):

| Order | Ref | Part | Notes |
| --- | --- | --- | --- |
| 1 | R1 | **MFP50SBBE52-50K** | Vertical axial in the **R1** footprint below **D3**; trim leads flush on the bottom. |
| 2 | D1, D2, D3 | **1N5407RL** | In the left column (**D1** top, **D2** middle, **D3** bottom). **Cathode band toward D1** (toward **K** / +12 V), as in [arduino-shield.jpg](arduino-shield/arduino-shield.jpg). |
| 3 | BZ1 | **PS1240P02BT**-class buzzer | Round **BZ1** footprint on the left; align **+** on the part with the **+** mark on the board. |
| 4 | SW1, SW2, SW3 | **1×3 pin sockets** (2.54 mm) | Three blocks on the **right** — **SW1** top, **SW2** middle, **SW3** bottom. |
| 5 | TH1, J1, J2, J3 | **2-pin** terminals (Molex **393800102** class) | Four outlined pairs left of the switch column — **TH1** at top, then **J1**, **J2**, **J3**. Note each **+** mark for field wiring. |
| 6 | Q1, Q2 | **TIP120** + **M3 nylon** bolt/nut | Mount **flat** on the copper zones labelled **Q1** (upper) and **Q2** (lower): tab against copper, leads bent down toward the **bottom** edge, then solder. Clamp each tab through the hole with an **M3 nylon bolt and nut only** — **metal screws or nuts will short 12 V** to the board or frame. **No add-on heatsinks.** |
| 7 | — | **Stacking header kit** (1528-1074-ND) | Top and bottom rows — long pins down toward the **Uno**. Kit: **2×6**, **2×8**, **1×10**. Align with a spare Uno before soldering every pin. |

Inspect joints under good light; fix bridges and cold joints. Compare the finished board to [arduino-shield.jpg](arduino-shield/arduino-shield.jpg) and the schematic PDF.

### Step 2 — Build the Arduino stack

Stack order (**bottom → top**):

1. **Arduino Uno R3** on the bench (its **USB** port is on the Uno only — use any stable orientation).
2. **Heatsink control shield** — match [arduino-shield.jpg](arduino-shield/arduino-shield.jpg) when populating; then press stacking headers fully onto the Uno; all pins should seat without force on bent leads.
3. **LCD shield (20×4, no buttons)** — press onto the control shield. Do **not** use an LCD Keypad Shield (firmware expects external switches on **D2–D4**).

Mount the stack in a **dry project box** on the harness or pack — never inside the ice cooler ([readme — dry locations](readme.md#12v-dc-safety-and-dry-locations)).

### Step 3 — Panel switches and NTC

**Panel switches (SW1–SW3):** The three **3-pin blocks** on the right of the board (see [placement diagram](arduino-shield/arduino-shield.jpg)) are **SW1** (top), **SW2** (middle), and **SW3** (bottom). For each block, crimp a **3-position socket** and three leads (0.5 mm²):

| Header | Switch | Wiring |
| --- | --- | --- |
| **SW1** | **100SP4T1B2M2QE** (temp up) | **Middle pin** → switch → **either outer pin** (both outers are **GND**). Active = grounded (**D2**). |
| **SW2** | **100SP4T1B2M2QE** (temp down) | Same — middle pin is **D3**. |
| **SW3** | **ANT13SECQE** (pump manual/auto) | Same — middle pin is **D4**. **ON** = grounded = manual pump override. |

The silkscreen **+** on each switch block marks the pin row orientation — use the **centre pin** for the Arduino signal, not the **+** mark, when wiring a simple two-terminal panel switch. Install **switch guards** on the panel, especially on SW3.

**NTC (TH1):** Top **2-pin** block in the terminal column (**TH1**). Connect the NTC cable to the pins marked on the board (**+** = sense / **A0** divider node, other = **GND**). Mount the **Bosch M12** sensor in the **collection manifold** ([readme — NTC placement](readme.md#coolant-plumbing)). Keep the connector and cable **dry** — only the sensor tip sees coolant.

### Step 4 — 12 V power and pump

Wire with **battery disconnected** and **fuses removed**.

1. **Common ground bus** — tie Arduino GND, battery (−), pump return, and Q1/Q2 emitter returns to one point (star ground in the box).
2. **Fused 12 V distribution** — **5 A max** inline fuse on the battery lead and on each branch: Arduino (barrel jack or VIN), pump **+** rail to **Q1**, spare **+** to **Q2** ([12 V power setup](readme.md#12v-power-setup)).
3. **Pump (Q1, D9)** — On **J1** (and related pump terminals), land **+12 V** on the pin marked **+**; switched/return on the other pin. **+12 V** (fused) → pump **+**; pump **−** → **Q1** low-side output; common **GND**. Use **≥1.5 mm²** wire. Do **not** pass pump current through Arduino pins.
4. **Spare output (Q2, D8)** — **J2** / **J3** same pattern: **+** silkscreen = **+12 V** in; other pin to load return through **Q2** if used.
5. **Polarity check** — verify **+12 V** and **GND** with a multimeter before connecting the battery.

See [Quick wiring reference](#quick-wiring-reference) and the [wiring diagram](readme.md#wiring-diagram).

### Step 5 — Load firmware

1. Connect the Uno to a PC via **USB** (stack can stay assembled; 12 V battery still **off**).
2. Open `firmware/pump-control.ino` in the Arduino IDE (or install from the [firmware folder](https://github.com/Supermagnum/heatsink/tree/main/firmware)).
3. Select board **Arduino Uno** and the correct serial port.
4. Upload. The **20×4 LCD** should show target temperature, sensed temperature, and PWM after boot.

### Step 6 — Bench test

With the **coolant loop filled and leak-checked** before long runs ([readme — assembly and testing](readme.md#coolant-plumbing)):

| Check | Action | Expected |
| --- | --- | --- |
| Power | Connect **fused 12 V**; USB optional for serial debug | LCD on; no excessive heating on wiring |
| NTC | Warm the sensor tip slightly (hand or warm water) | Sensed temperature on LCD changes smoothly |
| SW1 / SW2 | Tap temp up/down | Target steps **15–25 °C** in **5 °C** steps |
| SW3 | Toggle pump override **ON** | Pump runs at full PWM; **OFF** returns to auto control |
| Pump auto | SW3 **OFF**; vary NTC temperature | PWM changes with temperature error |
| Alarm | Simulate over-temp (>30 °C for 2 min) or heat sensor | Buzzer on **D7** sounds |
| 12 V load | Run pump at duty for several minutes | Q1 tab warm but stable; fuses do not blow; no melt/smoke |

Monitor the first field runs for leaks, fuse trips, and connector heat. Fix any weeping coolant joints before extended use.

---

## Ordering the PCB from Gerber files

Production-ready Gerbers for the heatsink control shield are in the repo — you do **not** need KiCad to order boards. Use the files in:

**[`arduino-shield/gerbers/`](arduino-shield/gerbers/)**

### What is in the folder

| File | Purpose |
| --- | --- |
| `arduino-shield-F_Cu.gbr` | Top copper |
| `arduino-shield-B_Cu.gbr` | Bottom copper |
| `arduino-shield-F_Mask.gbr` / `B_Mask.gbr` | Solder mask (top / bottom) |
| `arduino-shield-F_Silkscreen.gbr` / `B_Silkscreen.gbr` | Silkscreen legend |
| `arduino-shield-F_Paste.gbr` / `B_Paste.gbr` | Solder paste (for SMT assembly only — ignore if you hand-solder) |
| `arduino-shield-Edge_Cuts.gbr` | Board outline |
| `arduino-shield-PTH.drl` | Plated through-hole drill hits |
| `arduino-shield-NPTH.drl` | Non-plated holes (if any) |
| `arduino-shield-job.gbrjob` | Job metadata (layer stack, thickness) — optional but helps some fabs |

Board spec from the job file: **2-layer FR4**, **1.6 mm** thick, outline roughly **92 × 61 mm** (Arduino Uno R3 shield form factor).

### How to submit to a PCB fab

1. **Download or clone** the repo and open `arduino-shield/gerbers/`.
2. **Select all** `.gbr` and `.drl` files in that folder (include both drill files).
3. **Zip** them into one archive (e.g. `arduino-shield-gerbers.zip`). Keep filenames unchanged — do not nest an extra subfolder unless the fab asks for it.
4. **Upload** the zip to a board house (e.g. JLCPCB, PCBWay, OSH Park, Aisler, or any fab that accepts standard Gerber + Excellon drill).
5. **Preview** the upload in the fab’s Gerber viewer before paying. Check outline, drill hits, and silkscreen alignment.
6. **Choose fab options** (typical for this board):

   | Option | Recommended |
   | --- | --- |
   | Layers | **2** |
   | Thickness | **1.6 mm** |
   | Material | **FR4** |
   | Copper weight | **1 oz** (default) |
   | Surface finish | **HASL** or **ENIG** (either is fine for through-hole) |
   | Solder mask | Any colour (default green is fine) |
   | Silkscreen | White or yellow on green mask |
   | PCB assembly / SMT | **No** — this shield is **through-hole**; you populate it yourself (see [Soldering and wire splicing](#soldering-and-wire-splicing)) |

7. **Quantity:** most fabs quote from **5 pcs** upward; one board is enough for a single suit, extras are spares.

### After the boards arrive

- Compare the bare PCB to [arduino-shield.pdf](arduino-shield/arduino-shield.pdf).
- Follow [Assembly instructions](#assembly-instructions) from Step 1 onward.

### Regenerating Gerbers (optional)

The committed Gerbers match the shield design at export time. To produce a new set you need **KiCad 9** and the project in `arduino-shield/` — open `arduino-shield.kicad_pcb`, run **File → Fabrication Outputs → Gerbers**, and plot to `gerbers/` with drill files included. Only do this if you maintain your own fork of the PCB; the repo’s `gerbers/` folder is the canonical release for ordering.

---

## Wire and cable (minimum soldering)

| Use | Spec | Length (typical) | Notes |
| --- | --- | --- | --- |
| **12 V power** — battery to Uno/shield, pump (+) via Q1, spare via Q2 | **1.5 mm²** (16 AWG) stranded, **≥5 A** | Container ↔ battery ↔ pump | Land on shield **screw terminals**. **5 A inline fuse** per branch. |
| **Pump return / load (−)** | Same as 12 V power | Same | Low-side through Q1/Q2; common GND bus. |
| **Panel switches SW1–SW3** | **0.5 mm²** (22 AWG) stranded | ~0.5–2 m per switch | **Crimp to 1×3 socket** on shield headers — no soldering at panel if you use pre-crimped leads. Wire **pin → switch → GND**. |
| **NTC (TH1)** | **0.5 mm²** twisted or shielded pair | Manifold → control box | Plug or screw to TH1 connector on shield; route away from pump motor and PWM power runs. |
| **Stack interconnect** | — | — | Uno ↔ control shield ↔ LCD shield via **1528-1074-ND** stacking headers on the control shield (solder one kit per bare PCB). |

**Connectors:** 1×3 **2.54 mm** socket housings + crimp pins for SW1–SW3; screw terminals on shield for 12 V and pump.

---

## Soldering and wire splicing

**Tools and consumables:**

- **20 W soldering iron** with a fine tip — enough for this PCB and signal wiring, not heavy power lugs
- **Proper solder** — rosin-core electrical solder (e.g. **60/40 tin/lead** or lead-free **Sn96.5**), fine diameter (~0.6–0.8 mm) for through-hole parts and splices
- **Wet sponge** for tip cleaning (keep it damp, not dripping) — standard bench practice alongside the NASA video below
- **Heat-shrink tubing** — **required on every soldered splice** (see below; not shown in the splice reference video)

If you order a **bare** control shield PCB, you will need to solder the through-hole parts (stacking headers, TIP120, R1, D1–D3, buzzer, and field connectors). Panel and 12 V wiring can mostly use **crimps and screw terminals**; any soldered splices must use proper technique **and** heat-shrink insulation so joints stay reliable and safe under vibration and humidity.

### How to solder

NASA training video — old but the workmanship standard is excellent:  
[https://www.youtube.com/watch?v=_RXugDd0xik](https://www.youtube.com/watch?v=_RXugDd0xik)

### How to splice wire properly

[https://www.youtube.com/watch?v=O-ymw7d_nYo](https://www.youtube.com/watch?v=O-ymw7d_nYo)

### Heat-shrink on splices

The splice video does **not** show finishing the joint — after soldering, **slide heat-shrink over the splice and shrink it fully** so no bare copper is exposed. Use tubing sized for your wire (typically slightly larger ID before shrinking); for 12 V runs, use heavier wall or double-layer shrink if the splice is in the harness. No exceptions for in-box or panel wiring.

Prefer **screw terminals or crimp connectors** on 12 V and switch runs where you can and skip splices entirely. When you must splice, follow the [splice video](#how-to-splice-wire-properly), then **always** heat-shrink. Work **de-energized** — battery disconnected and fuses out — see [12 V safety and enclosure](#12-v-safety-and-enclosure).

---

## Quick wiring reference

```
Stack:  Uno R3  →  control shield  →  LCD shield (no buttons)

AREF — R1 (50K) — A0 — TH1 (Bosch M12) — GND   (on control shield)

SW1/SW2/SW3:  header pin → switch → GND  (D2 / D3 / D4)  + switch guards

D9 → Q1 → pump (+)     pump (−) → GND
D8 → Q2 → spare load
D7 → buzzer
```

---

## Suggested order checklist

- [ ] Arduino Uno R3  
- [ ] Heatsink control shield — order bare PCB from [Gerber files](component-list.md#ordering-the-pcb-from-gerber-files) or populate one you already have  
- [ ] DigiKey bare-shield kit — [1528-1074-ND](https://www.digikey.com/en/products/result?keywords=1528-1074-ND) + [MFP50SBBE52-50K-ND](https://www.digikey.com/en/products/result?keywords=MFP50SBBE52-50K-ND) + 3× [1N5407RL-ND](https://www.digikey.com/en/products/result?keywords=1N5407RL-ND) (or 3× [1N5407RLG-ND](https://www.digikey.com/en/products/result?keywords=1N5407RLG-ND)) — see [DigiKey quick order](component-list.md#digikey-quick-order-bare-shield-populate)  
- [ ] 2× **TIP120** (Q1, Q2) + 2× **M3 nylon** bolt/nut + buzzer — see [Control shield](component-list.md#control-shield-included-in-stack)  
- [ ] LCD shield 20×4 **without buttons**  
- [ ] 1× Bosch M12 NTC + M12 tap + thread sealant  
- [ ] 2× 100SP4T1B2M2QE + guards  
- [ ] 1× ANT13SECQE + guard  
- [ ] 12 V wire (1.5 mm²) + switch leads (0.5 mm²) + crimp housings + fuses (5 A)  
- [ ] **20 W soldering iron**, **rosin-core solder**, **wet sponge**, and **heat-shrink tubing** (only if populating a bare control shield or making splices) — see [Soldering and wire splicing](component-list.md#soldering-and-wire-splicing)

---

## 12 V safety and enclosure

- **Q1 / Q2 mounting:** Use **M3 nylon bolt and nut** only at the TIP120 tabs. **Metal** screws, nuts, or washers can bridge **12 V** to ground or the enclosure and blow fuses or damage the board.
- **Control unit** (Uno + heatsink shield + LCD stack, battery, and dry-side wiring) must stay **dry** — mount in a project box on the harness or pack, **not** inside the ice cooler.
- **Fused 12 V** (5 A max per branch), **1.5 mm²** pump feeds, correct polarity, common ground — see [12V DC safety and dry locations](readme.md#12v-dc-safety-and-dry-locations) in the readme.
- Only the **submersible pump** and coolant path belong in the wet zone; seal lid glands for hose and pump power; keep NTC connector and Arduino wiring in the dry enclosure.

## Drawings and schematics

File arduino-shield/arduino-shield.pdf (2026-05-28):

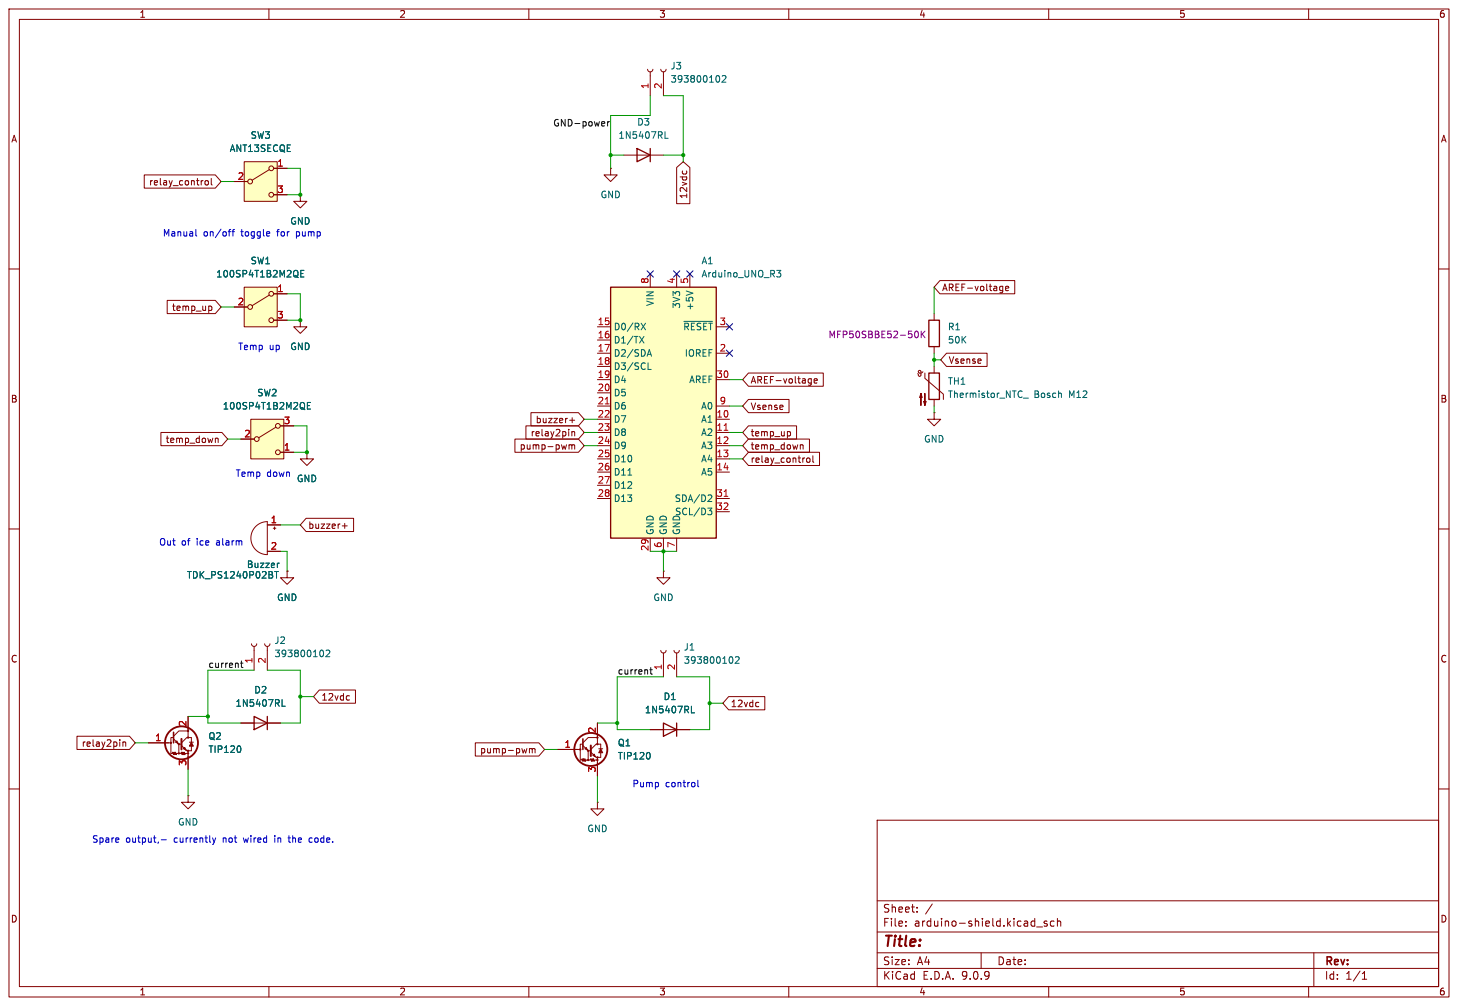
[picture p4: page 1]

Id: 1/1 Title: File: arduino-shield.kicad_sch Sheet: /

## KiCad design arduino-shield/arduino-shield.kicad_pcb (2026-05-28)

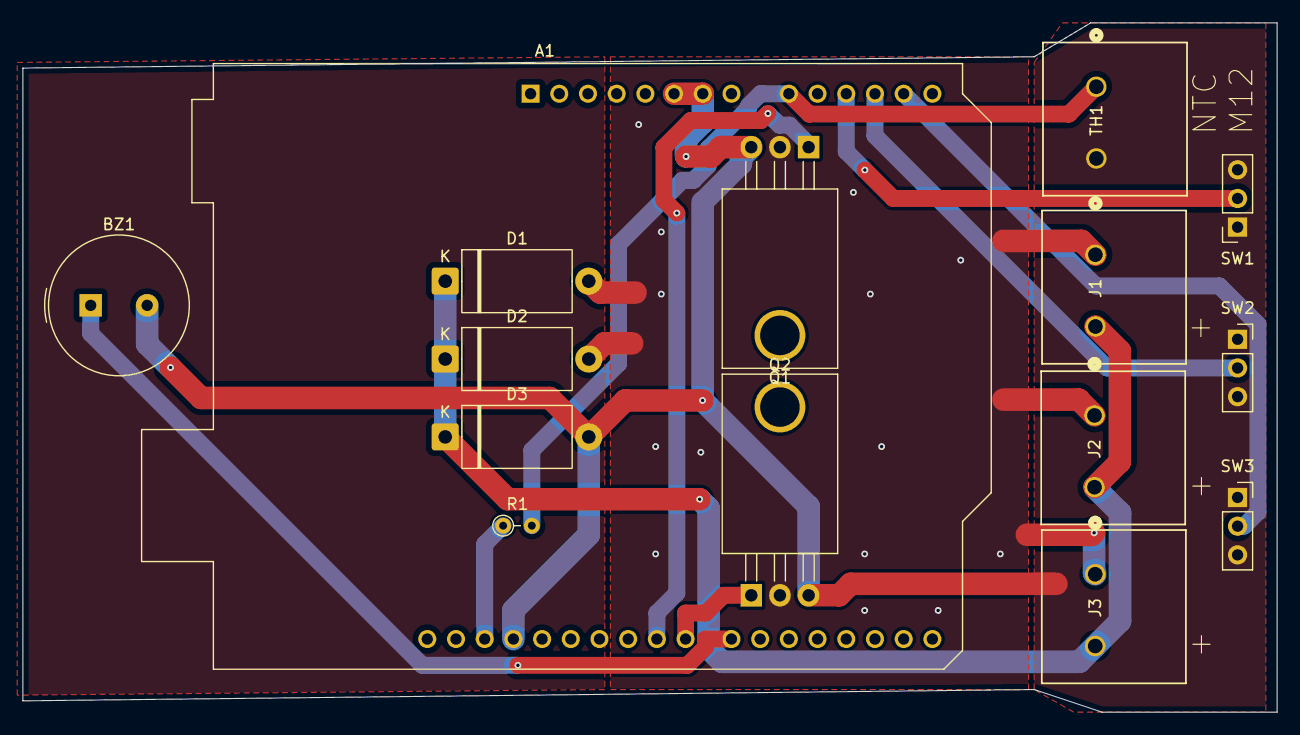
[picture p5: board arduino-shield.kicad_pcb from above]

Board: 2 copper layers, 111.0 x 61.0 mm, 15 parts (0 on the bottom side), 11 nets.

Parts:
A1: Arduino_UNO_R3; Arduino_UNO_R3_
BZ1: Buzzer; Buzzer_TDK_PS1240P02BT_D12.2mm_H6.5mm
D1, D2, D3: 1N5407RL; D_DO-27_P12.70mm_Horizontal
J1, J2, J3: 393800102; CONN2_0393800102_524X492_MOL
Q1, Q2: TIP120; TO-220-3_Horizontal_TabDown
R1: 50K; R_Axial_DIN0204_L3.6mm_D1.6mm_P2.54mm_Vertical
SW1, SW2: 100SP4T1B2M2QE; PinSocket_1x03_P2.54mm_Vertical
SW3: ANT13SECQE; PinSocket_1x03_P2.54mm_Vertical
TH1: Thermistor_NTC_ Bosch M12; CONN2_0393800102_524X492_MOL

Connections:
12vdc: D1.1 (K), D2.1 (K), D3.1 (K), J1.2, J2.2, J3.2
/current: D1.2 (A), D2.2 (A), J1.1, J2.1, J3.1, Q1.2 (C), Q2.2 (C)
AREF-voltage: A1.30 (AREF), R1.1
GND: A1.6 (GND), A1.7 (GND), A1.29 (GND), BZ1.2 (-), D3.2 (A), Q1.3 (E), Q2.3 (E), SW1.1 (A), SW1.3 (C), SW2.1 (C), SW2.3 (A), SW3.1 (A), SW3.3 (C), TH1.2
Vsense: A1.9 (A0), R1.2, TH1.1
buzzer+: A1.22 (D7), BZ1.1 (+)
pump-pwm: A1.24 (D9), Q1.1 (B)
relay2pin: A1.23 (D8), Q2.1 (B)
relay_control: A1.13 (A4), SW3.2 (B)
temp_down: A1.12 (A3), SW2.2 (B)
temp_up: A1.11 (A2), SW1.2 (B)

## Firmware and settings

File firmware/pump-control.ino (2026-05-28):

#include <LiquidCrystal.h>

// LCD1602 LDC
// ── Pin assignments ───────────────────────────────────────────────────────────
// LCD uses pins 12, 11, 10, 6, 5, 13
// Switches and other I/O use pins 2, 3, 4, 7, 8, 9 — no conflicts
const int ntcPin              = A0;  // Vsense — R1/TH1; TH1 in collection manifold at suit
const int pwmPin              = 9;   // PWM pin — Q1 TIP120 pump driver on shield
const int alarmPin            = 7;   // Buzzer — out-of-ice alarm (D7 on shield)
const int sparePin            = 8;   // TIP120 Q2 — spare 12V output on shield
const int tempUpSwitch        = 2;   // Momentary switch: increase target temperature
const int tempDownSwitch      = 3;   // Momentary switch: decrease target temperature
const int pumpOverrideSwitch  = 4;   // Maintained toggle: manual pump override (Q1 / D9)

// Switches wire pin-to-GND; internal pull-ups keep the pin HIGH until closed. Active = LOW.
const int SWITCH_ACTIVE = LOW;

// ── Hardware constants ────────────────────────────────────────────────────────
// NTC divider: AREF-voltage — R1 (50K) — A0 — TH1 (Bosch M12 NTC) — GND
// AREF pin shares the divider supply; ADC uses it as the reference voltage.
const int   resistorValue = 50000;  // R1, 50k ohm fixed resistor (top of divider)
const int   debounceDelay = 50;     // Switch debounce delay (ms)

// ── Smoothing constants ───────────────────────────────────────────────────────
const float tau   = 15.0;           // Response time constant (seconds)
const float dt    = 0.5;            // Loop interval (seconds)
const float alpha = dt / tau;       // Exponential smoothing factor

// ── NTC calibration table (Bosch M12) ────────────────────────────────────────
const int  tempValues[]       = {-40, -20, -10,  0,  10,   20,   30,   40,   50};
const long resistanceValues[] = {45313, 15462, 9397, 5896, 3792, 2500, 1707, 1175, 834};
const int  calibrationPoints  = 9;

// ── State variables ───────────────────────────────────────────────────────────
int           targetTemp       = 15;
float         readTemp         = 20.0;
int           pwmValue         = 0;
bool          pumpManualActive = false;
unsigned long lastDebounceTime = 0;
bool          tempUpPrev       = false;
bool          tempDownPrev     = false;

// ── Alarm output timing (non-blocking) ───────────────────────────────────────
const unsigned long alarmDelay    = 120000UL;
unsigned long       overTempStart = 0;
bool                overTempActive = false;

// ── LCD setup ─────────────────────────────────────────────────────────────────
LiquidCrystal lcd(12, 11, 10, 6, 5, 13);

// ─────────────────────────────────────────────────────────────────────────────
void setup() {
  pinMode(ntcPin,             INPUT);
  analogReference(EXTERNAL);

  pinMode(pwmPin,             OUTPUT);
  pinMode(alarmPin,           OUTPUT);
  pinMode(sparePin,           OUTPUT);
  pinMode(tempUpSwitch,       INPUT_PULLUP);
  pinMode(tempDownSwitch,     INPUT_PULLUP);
  pinMode(pumpOverrideSwitch, INPUT_PULLUP);

  digitalWrite(alarmPin, LOW);
  digitalWrite(sparePin, LOW);
  analogWrite(pwmPin, 0);

  lcd.begin(20, 4);
  lcd.clear();

  readTemp = getTemperature();
  Serial.begin(9600);
}

// ─────────────────────────────────────────────────────────────────────────────
void loop() {
  float currentTemp = getTemperature();
  readTemp += alpha * (currentTemp - readTemp);

  unsigned long now = millis();

  bool tempUpActive   = digitalRead(tempUpSwitch) == SWITCH_ACTIVE;
  bool tempDownActive = digitalRead(tempDownSwitch) == SWITCH_ACTIVE;

  if (tempUpActive && !tempUpPrev && (now - lastDebounceTime) > debounceDelay) {
    targetTemp = min(targetTemp + 5, 25);
    lastDebounceTime = now;
  }

  if (tempDownActive && !tempDownPrev && (now - lastDebounceTime) > debounceDelay) {
    targetTemp = max(targetTemp - 5, 15);
    lastDebounceTime = now;
  }

  tempUpPrev   = tempUpActive;
  tempDownPrev = tempDownActive;

  pumpManualActive = (digitalRead(pumpOverrideSwitch) == SWITCH_ACTIVE);

  updatePWM();

  if (readTemp > 30.0) {
    if (!overTempActive) {
      overTempActive = true;
      overTempStart  = millis();
    } else if ((millis() - overTempStart) >= alarmDelay) {
      digitalWrite(alarmPin, HIGH);
    }
  } else {
    overTempActive = false;
    digitalWrite(alarmPin, LOW);
  }

  updateLCD();

  Serial.print("Target: ");  Serial.print(targetTemp);
  Serial.print(" Read: ");   Serial.print(readTemp);
  Serial.print(" PWM: ");    Serial.print(pwmValue);
  Serial.print(" Manual: "); Serial.println(pumpManualActive ? "ON" : "OFF");

  delay((unsigned long)(dt * 1000));
}

// ─────────────────────────────────────────────────────────────────────────────
float getTemperature() {
  int analogValue = analogRead(ntcPin);
  if (analogValue >= 1022) return -40.0;

  // Divider supply and ADC reference are both AREF-voltage, so use raw counts.
  float resistance = resistorValue * ((float)analogValue / (1023.0 - analogValue));

  if (resistance >= resistanceValues[0])                    return (float)tempValues[0];
  if (resistance <= resistanceValues[calibrationPoints - 1]) return (float)tempValues[calibrationPoints - 1];

  for (int i = 0; i < calibrationPoints - 1; i++) {
    if (resistance <= resistanceValues[i] && resistance >= resistanceValues[i + 1]) {
      float t = (float)tempValues[i] +
                (resistance - (float)resistanceValues[i]) *
                ((float)(tempValues[i + 1] - tempValues[i]) /
                 (float)(resistanceValues[i + 1] - resistanceValues[i]));
      return t;
    }
  }
  return -40.0;
}

// ─────────────────────────────────────────────────────────────────────────────
void updatePWM() {
  if (pumpManualActive) {
    pwmValue = 255;
  } else if (readTemp > (float)targetTemp) {
    pwmValue = (int)map((long)(readTemp * 10),
                        (long)(targetTemp * 10),
                        (long)((targetTemp + 20) * 10),
                        26, 255);
    pwmValue = constrain(pwmValue, 26, 255);
  } else {
    pwmValue = 0;
  }
  analogWrite(pwmPin, pwmValue);
}

// ─────────────────────────────────────────────────────────────────────────────
void updateLCD() {
  lcd.setCursor(0, 0);
  lcd.print("Target:  ");
  lcd.print(targetTemp);
  lcd.print((char)223);
  lcd.print("C   ");

  lcd.setCursor(0, 1);
  lcd.print("Coolant: ");
  lcd.print(readTemp, 1);
  lcd.print((char)223);
  lcd.print("C   ");

  lcd.setCursor(0, 2);
  lcd.print("Pump PWM:");
  lcd.print(map(pwmValue, 0, 255, 0, 100));
  lcd.print("%    ");

  lcd.setCursor(0, 3);
  lcd.print("Manual: ");
  lcd.print(pumpManualActive ? "ON " : "OFF");
  lcd.print(" Alarm:");
  lcd.print(digitalRead(alarmPin) ? "ON " : "OFF");
}

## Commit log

2023-08-16 Update readme.txt
    Update with maths to solve for ambient temperature.
2026-05-24 Revise readme for clarity and organization
    Updated the readme to enhance clarity and structure, added sections for thermal calculations, required hardware, and pump selection, and improved formatting for better readability.
2026-05-24 Refactor pump control code and improve readability
2026-05-28 Document hardware and firmware updates; add Arduino shield and readme TOC.
    Align pump-control with ground-active buttons, AREF NTC divider, transistor outputs, and manual pump override; expand readme with plumbing, coolant, and shield PDF links.
    [arduino-shield-B_Cu.gbr, arduino-shield-B_Mask.gbr, arduino-shield-B_Paste.gbr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]
2026-05-28 Update readme coolant guidance and wiring diagram.
    Recommend 25-30% inhibited propylene glycol, document ElectroCool as optional, and expand the wiring diagram with pin summary and shield PDF reference.
2026-05-28 Clarify NTC placement, parts list, and 5A fuse guidance in readme.
    Mount TH1 on the collection manifold at the suit; document LCD, TIP120 heatsink zones, and per-branch 5A fuses in the hardware and power sections.
2026-05-28 Add component list, safety docs, and switch-oriented firmware updates.
    Document stacked Uno build, panel switch BOM, 12V safety, soldering guidance,
    and copper thermal zones; align firmware with momentary/toggle switch behavior.
    [arduino-shield.kicad_pcb]
2026-05-28 Document Gerber ordering and add soldering guides to TOC.
    Explain how to submit shield Gerbers to a fab, split solder/splice/heat-shrink
    into linked sections, and nest those entries in the readme table of contents.
2026-05-28 Expand BOM and assembly docs; add shield placement image.
    Document DigiKey line items, step-by-step assembly with arduino-shield.jpg,
    nylon M3 mounting for Q1/Q2, and updated shield Gerbers/KiCad exports.
    [arduino-shield-B_Cu.gbr, arduino-shield-B_Mask.gbr, arduino-shield-B_Paste.gbr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]
2026-05-28 Fix shield placement guide: no USB on control shield.
    Orient the bare board using silkscreen refs and arduino-shield.jpg
    instead of the Uno USB port.
2026-05-28 Update shield layout, placement image, and Gerbers.
    Refresh KiCad PCB, silkscreen, and fabrication outputs to match the
    current board design shown in arduino-shield.jpg.
    [arduino-shield-B_Cu.gbr, arduino-shield-B_Mask.gbr, arduino-shield-B_Paste.gbr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]
